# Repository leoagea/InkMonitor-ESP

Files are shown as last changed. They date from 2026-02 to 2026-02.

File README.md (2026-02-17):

# InkMonitor-ESP

InkMonitor-ESP is a lightweight temperature and humidity monitoring device built around an ESP microcontroller and an e‑paper display. This repository contains the hardware design files (KiCad) for the PCB and supporting assets.

## Highlights

- Low‑power ESP‑based monitoring platform
- E‑paper display for always‑on status with minimal power draw
- KiCad project files, BOM export, and board backups included

## Repository contents

- [PCB/](PCB/) — KiCad project, board/schematic, BOM, CAD assets, and exports
- [changelog.md](changelog.md) — project changes

## Hardware overview

The design targets a compact ESP‑based module (ESP32‑S3 class) paired with a temperature/humidity sensor and a small e‑paper display. The exact parts and footprints are defined in the KiCad files.

If you want to review or edit the design, open the KiCad project file:

- [PCB/InkMonitor-ESP.kicad_pro](PCB/InkMonitor-ESP.kicad_pro)

## Renders

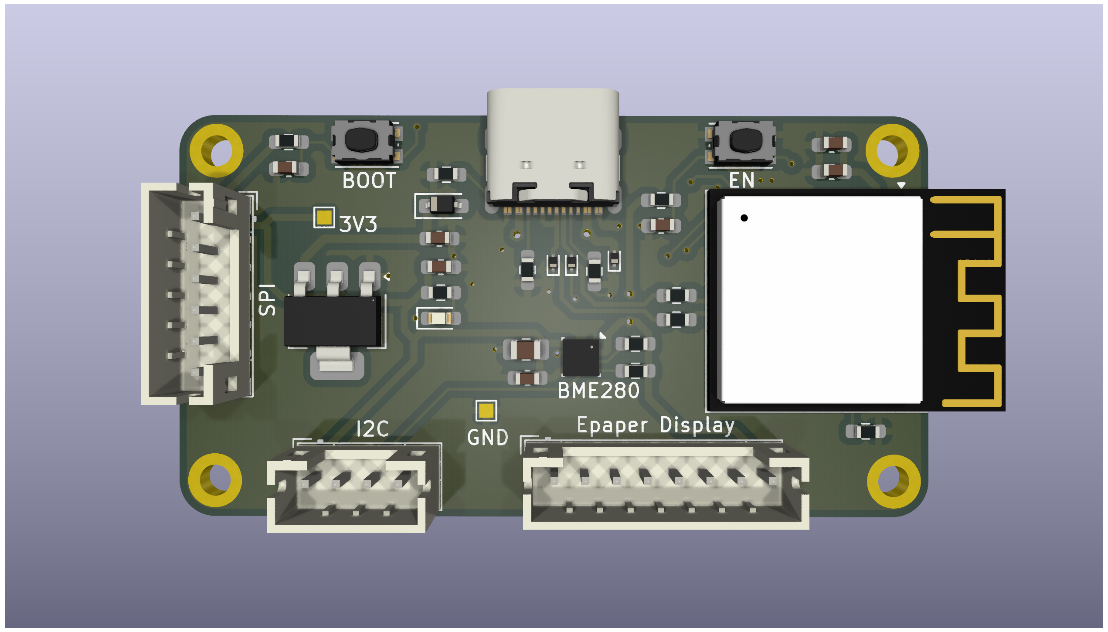
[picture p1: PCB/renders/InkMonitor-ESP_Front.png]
InkMonitor-ESP Front

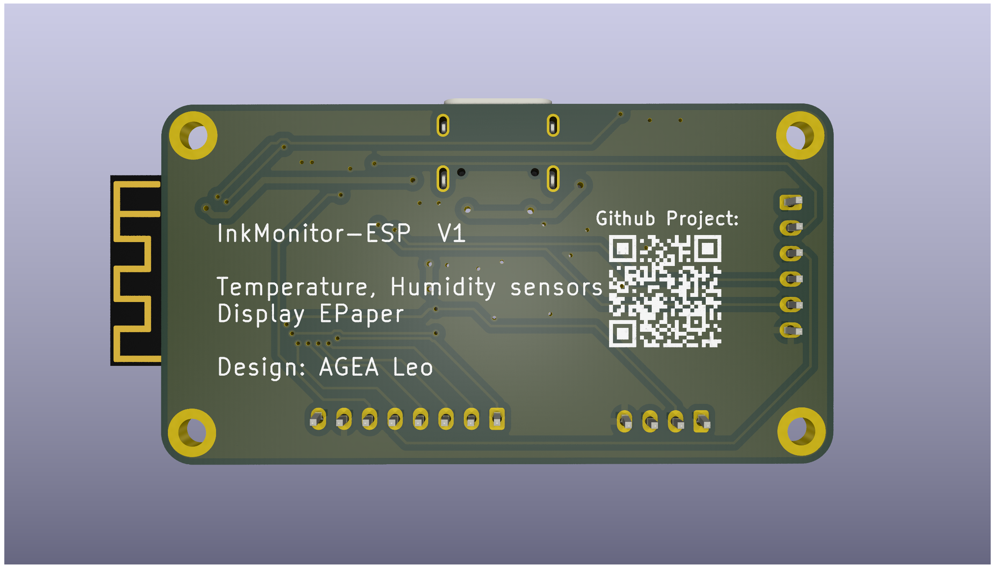
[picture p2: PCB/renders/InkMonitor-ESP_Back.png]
InkMonitor-ESP Back


1. Open the project file: [PCB/InkMonitor-ESP.kicad_pro](PCB/InkMonitor-ESP.kicad_pro).
2. Review the schematic: [PCB/InkMonitor-ESP.kicad_sch](PCB/InkMonitor-ESP.kicad_sch).
3. Review the PCB layout: [PCB/InkMonitor-ESP.kicad_pcb](PCB/InkMonitor-ESP.kicad_pcb).

## Firmware

WIP

## License

See [LICENSE](LICENSE).

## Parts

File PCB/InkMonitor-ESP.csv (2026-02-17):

Reference | Qty | Value | LCSC | Footprint | Datasheet
C1,C2,C5 | 3 | 22µ | C86295 | Capacitor_SMD:C_0603_1608Metric_Pad1.08x0.95mm_HandSolder | ~
C3,C6,C7,C8 | 4 | 100n | C14663 | Capacitor_SMD:C_0603_1608Metric_Pad1.08x0.95mm_HandSolder | ~
C4 | 1 | 1µ | C376929 | Capacitor_SMD:C_0805_2012Metric_Pad1.18x1.45mm_HandSolder | ~
D1 | 1 | BAT760-7 | C27636120 | Diode_SMD:D_SOD-323_HandSoldering | ~
D2,D3,D4 | 3 | ESD9B5.0ST5G | C111566 | Diode_SMD:D_SOD-923 | https://www.onsemi.com/pub/Collateral/ESD9B-D.PDF
D5 | 1 | RED | C19171390 | LED_SMD:LED_0603_1608Metric_Pad1.05x0.95mm_HandSolder | ~
J1 | 1 | USB_C_Receptacle_USB2.0_14P | C2765186 | Connector_USB:USB_C_Receptacle_GCT_USB4105-xx-A_16P_TopMnt_Horizontal | https://www.usb.org/sites/default/files/documents/usb_type-c.zip
J2 | 1 | Epaper Display |  | Connector_JST:JST_PH_B8B-PH-K_1x08_P2.00mm_Vertical | ~
J3 | 1 | SPI |  | Connector_JST:JST_PH_B6B-PH-K_1x06_P2.00mm_Vertical | ~
J4 | 1 | I2C |  | Connector_JST:JST_PH_B4B-PH-K_1x04_P2.00mm_Vertical | ~
R1 | 1 | 1M | C22935 | R_0603_1608Metric_Pad0.98x0.95mm_HandSolder | ~
R2,R3 | 2 | 22R | C23345 | R_0603_1608Metric_Pad0.98x0.95mm_HandSolder | ~
R4 | 1 | 2k | C2907137 | Resistor_SMD:R_0603_1608Metric_Pad0.98x0.95mm_HandSolder | ~
R5,R6 | 2 | 5,1k | C23186 | R_0603_1608Metric_Pad0.98x0.95mm_HandSolder | ~
R7,R8,R9,R10,R11 | 5 | 10k | C2930027 | R_0603_1608Metric_Pad0.98x0.95mm_HandSolder | ~
SW1,SW2 | 2 | SW_Push | C49393608 | Button_Switch_SMD:SW_Push_1P1T_NO_CK_KMR2 | ~
U1 | 1 | AMS1117-3.3 | C347222 | Package_TO_SOT_SMD:SOT-223 | http://www.advanced-monolithic.com/pdf/ds1117.pdf
U2 | 1 | BME280 |  | Package_LGA:Bosch_LGA-8_2.5x2.5mm_P0.65mm_ClockwisePinNumbering | https://www.bosch-sensortec.com/media/boschsensortec/downloads/datasheets/bst-bme280-ds002.pdf
U3 | 1 | ESP32-S3-MINI-1 |  | RF_Module:ESP32-S2-MINI-1 | https://www.espressif.com/sites/default/files/documentation/esp32-s3-mini-1_mini-1u_datasheet_en.pdf

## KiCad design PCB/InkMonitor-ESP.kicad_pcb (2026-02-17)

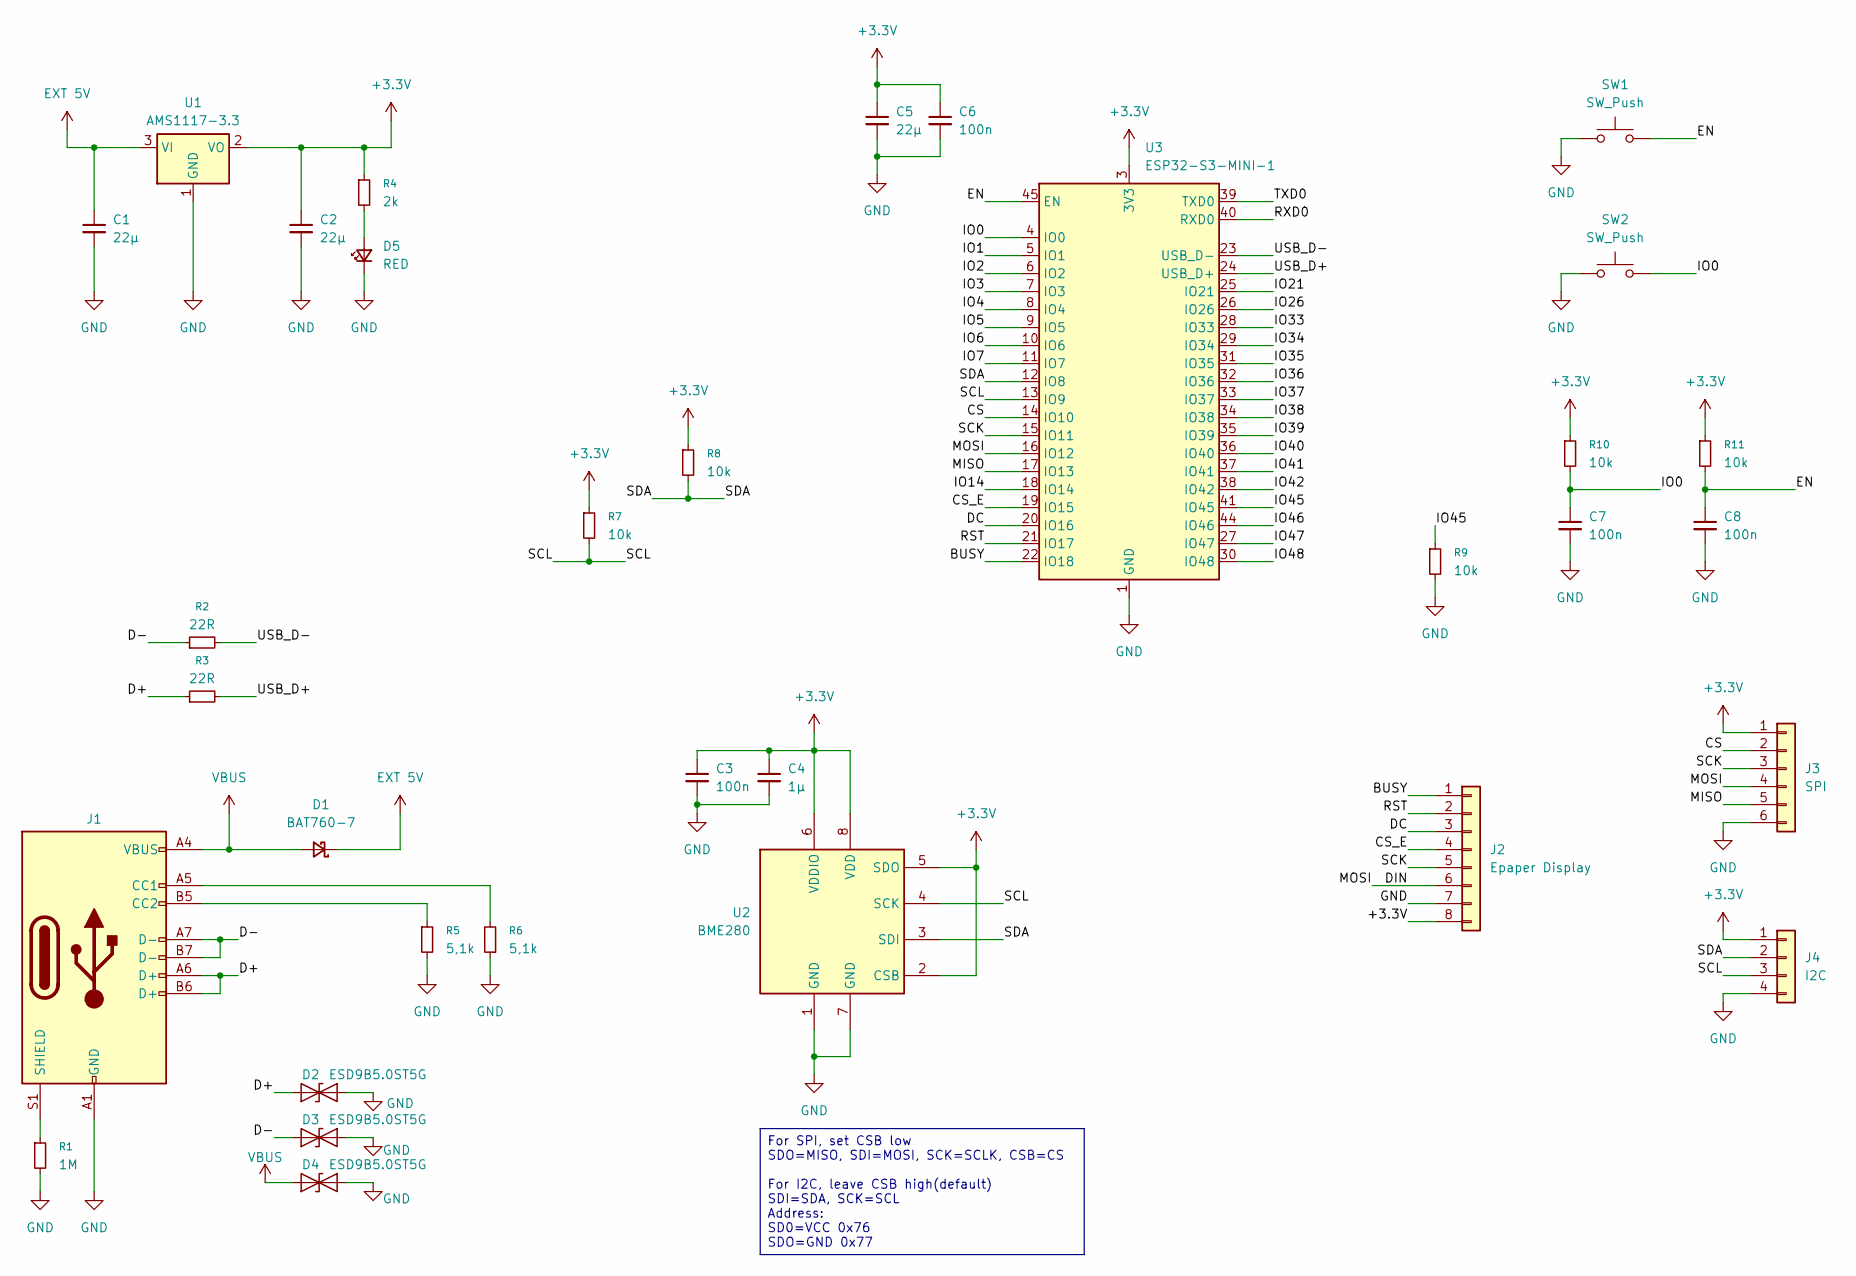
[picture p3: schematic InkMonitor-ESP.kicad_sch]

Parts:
C1, C2, C5: 22µ; C_0603_1608Metric_Pad1.08x0.95mm_HandSolder; LCSC C86295
C3, C6, C7, C8: 100n; C_0603_1608Metric_Pad1.08x0.95mm_HandSolder; LCSC C14663
C4: 1µ; C_0805_2012Metric_Pad1.18x1.45mm_HandSolder; LCSC C376929
D1: BAT760-7; D_SOD-323_HandSoldering; LCSC C27636120
D2, D3, D4: ESD9B5.0ST5G; D_SOD-923; LCSC C111566
D5: RED; LED_0603_1608Metric_Pad1.05x0.95mm_HandSolder; LCSC C19171390
J1: USB_C_Receptacle_USB2.0_14P; USB_C_Receptacle_GCT_USB4105-xx-A_16P_TopMnt_Horizontal; LCSC C2765186
J2: Epaper Display; JST_PH_B8B-PH-K_1x08_P2.00mm_Vertical
J3: SPI; JST_PH_B6B-PH-K_1x06_P2.00mm_Vertical
J4: I2C; JST_PH_B4B-PH-K_1x04_P2.00mm_Vertical
R1: 1M; R_0603_1608Metric_Pad0.98x0.95mm_HandSolder; LCSC C22935
R2, R3: 22R; R_0603_1608Metric_Pad0.98x0.95mm_HandSolder; LCSC C23345
R4: 2k; R_0603_1608Metric_Pad0.98x0.95mm_HandSolder; LCSC C2907137
R5, R6: 5,1k; R_0603_1608Metric_Pad0.98x0.95mm_HandSolder; LCSC C23186
R7, R8, R9, R10, R11: 10k; R_0603_1608Metric_Pad0.98x0.95mm_HandSolder; LCSC C2930027
SW1, SW2: SW_Push; SW_Push_1P1T_NO_CK_KMR2; LCSC C49393608
U1: AMS1117-3.3; SOT-223; LCSC C347222
U2: BME280; Bosch_LGA-8_2.5x2.5mm_P0.65mm_ClockwisePinNumbering
U3: ESP32-S3-MINI-1; ESP32-S2-MINI-1

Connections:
+3.3V: C2.1, C3.1, C4.1, C5.1, C6.1, J2.8, J3.1, J4.1, R4.1, R7.1, R8.1, R10.1, R11.1, U1.2 (VO), U2.2 (CSB), U2.5 (SDO), U2.6 (VDDIO), U2.8 (VDD), U3.3 (3V3); also elsewhere on the board
/BUSY: J2.1, U3.22 (IO18)
/CS: J3.2, U3.14 (IO10)
/CS_E: J2.4, U3.19 (IO15)
/D+: D2.2 (A2), J1.A6 (D+), J1.B6 (D+), R3.1
/D-: D3.2 (A2), J1.A7 (D-), J1.B7 (D-), R2.1
/DC: J2.3, U3.20 (IO16)
/DIN: J2.6, J3.4, U3.16 (IO12)
/EN: C8.1, R11.2, SW1.2, U3.45 (EN)
/IO0: C7.1, R10.2, SW2.2, U3.4 (IO0)
/IO1: U3.5 (IO1)
/IO2: U3.6 (IO2)
/IO3: U3.7 (IO3)
/IO4: U3.8 (IO4)
/IO5: U3.9 (IO5)
/IO6: U3.10 (IO6)
/IO7: U3.11 (IO7)
/IO14: U3.18 (IO14)
/IO21: U3.25 (IO21)
/IO26: U3.26 (IO26)
/IO33: U3.28 (IO33)
/IO34: U3.29 (IO34)
/IO35: U3.31 (IO35)
/IO36: U3.32 (IO36)
/IO37: U3.33 (IO37)
/IO38: U3.34 (IO38)
/IO39: U3.35 (IO39)
/IO40: U3.36 (IO40)
/IO41: U3.37 (IO41)
/IO42: U3.38 (IO42)
/IO45: R9.1, U3.41 (IO45)
/IO46: U3.44 (IO46)
/IO47: U3.27 (IO47)
/IO48: U3.30 (IO48)
/MISO: J3.5, U3.17 (IO13)
/RST: J2.2, U3.21 (IO17)
/RXD0: U3.40 (RXD0)
/SCK: J2.5, J3.3, U3.15 (IO11)
/SCL: J4.3, R7.2, U2.4 (SCK), U3.13 (IO9)
/SDA: J4.2, R8.2, U2.3 (SDI), U3.12 (IO8)
/TXD0: U3.39 (TXD0)
/USB_D+: R3.2, U3.24 (USB_D+)
/USB_D-: R2.2, U3.23 (USB_D-)
EXT 5V: C1.1, D1.1 (K), U1.3 (VI)
GND: C1.2, C2.2, C3.2, C4.2, C5.2, C6.2, C7.2, C8.2, D2.1 (A1), D3.1 (A1), D4.1 (A1), D5.1 (K), J1.A1 (GND), J1.A12 (GND), J1.B1 (GND), J1.B12 (GND), J2.7, J3.6, J4.4, R1.2, R5.2, R6.1, R9.2, SW1.1, SW2.1, U1.1 (GND), U2.1 (GND), U2.7 (GND), U3.1 (GND), U3.2 (GND), U3.42 (GND), U3.43 (GND), U3.46 (GND), U3.47 (GND), U3.48 (GND), U3.49 (GND), U3.50 (GND), U3.51 (GND), U3.52 (GND), U3.53 (GND), U3.54 (GND), U3.55 (GND), U3.56 (GND), U3.57 (GND), U3.58 (GND), U3.59 (GND), U3.60 (GND), U3.61 (GND), U3.62 (GND), U3.63 (GND), U3.64 (GND), U3.65 (GND); also elsewhere on the board
unnamed: D5.2 (A), R4.2
unnamed: J1.A5 (CC1), R6.2
unnamed: J1.B5 (CC2), R5.1
unnamed: J1.S1 (SHIELD), R1.1
VBUS: D1.2 (A), D4.2 (A2), J1.A4 (VBUS), J1.A9 (VBUS), J1.B4 (VBUS), J1.B9 (VBUS)

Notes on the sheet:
For SPI, set CSB low SDO=MISO, SDI=MOSI, SCK=SCLK, CSB=CS For I2C, leave CSB high(default) SDI=SDA, SCK=SCL Address: SD0=VCC 0x76 SDO=GND 0x77

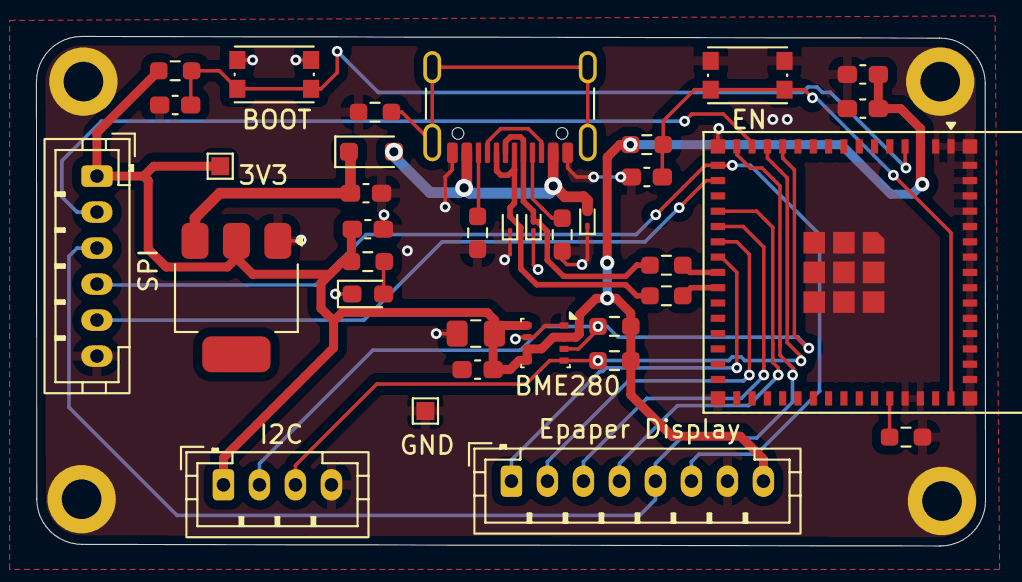
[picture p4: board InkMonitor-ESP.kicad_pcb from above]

Board: 2 copper layers, 52.7 x 28.3 mm, 35 parts (0 on the bottom side), 25 nets.

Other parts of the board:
3V3: TestPoint_Pad_1.0x1.0mm
GND: TestPoint_Pad_1.0x1.0mm

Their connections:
+3.3V: 3V3.1; also elsewhere on the board
GND: GND.1; also elsewhere on the board

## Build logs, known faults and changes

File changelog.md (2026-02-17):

# Changelog

## [Unreleased]
### Schematic
- 

### PCB
- 

### BOM
- 

## [v1.0] - 2026-02-17
### Schematic
- Initial design.

### PCB
- Initial layout.

### BOM
- Initial component selection.

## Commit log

2026-02-17 V1, schematic + pcb
    [InkMonitor-ESP.kicad_pcb, InkMonitor-ESP.kicad_sch]
2026-02-17 Cad esp32-s3-mini
2026-02-17 V1 BOM
    [InkMonitor-ESP.csv]
